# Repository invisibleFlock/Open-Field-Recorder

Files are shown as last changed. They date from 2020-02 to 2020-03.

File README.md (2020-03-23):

Welcome to the project page for the OFR

# What is OFR:

OFR is the Open Field Recorder created by Invisible Flock (and friends). 

With support and in collaboration with Bournemouth University and Professor Amanda H Korstjens from [LEAP](https://go-leap.wixsite.com/home/amanda-korstjens).

It is an open hardware and software platform for remote long form bio-acoustic recording. 

It is created for *sound artists, conservationists, scientist* and anyone who wants or needs to record audio and environmental data for long periods of time in inhospitable environments. 

It is modular, hackable, meshable and useful in a wide series of situations and applications.

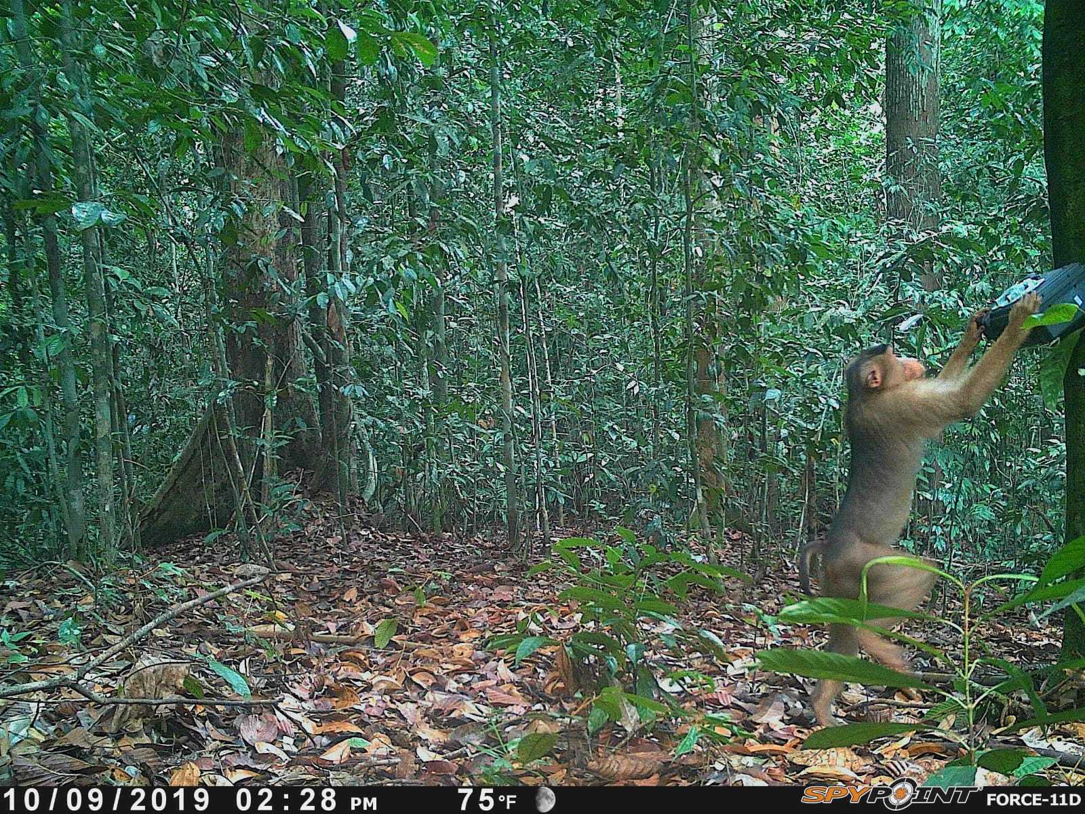
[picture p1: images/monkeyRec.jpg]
monkey with REcorder


# Why does it exit:

The OFR was created by Invisible Flock to solve a specific need we had whilst recording large sections of a rainforest in Sumatra. 

We needed recorders that would function in the difficult conditions of the forest for long periods of time in order to monitor the biodiversity of the area and that we could sync together to create large scale multichannel sound installations with audio quality as close to our main field recorders as possible.

The OFR for us was an attempt to bridge a gap that was not currently being fulfilled by other products on the market allowing us to record stereo audio from high quality microphones that were synced via GPS. 

Whilst there are other excellent products that already exist for bio-acoustic monitoring, most notably the [audio-moth](https://www.openacousticdevices.info/), the [solo](https://solo-system.github.io/home.html), and the [swift](https://www.birds.cornell.edu/ccb/wp-content/uploads/2016/09/SWIFT-SD-Card-Formatting-Protocol.pdf) none provided us with the specifics we wanted for this project but you may find they are good fit for you depending on your aims.

# What's inside it:

Expand ability and flexibility were important for us in this design and was the ability for other users to build on it and hack the recorder into their own needs. Version 1.1 is built on the [Spresense](https://developer.sony.com/develop/spresense/) a multicore development board platform by Sony which is programmable via the Arduino IDE.

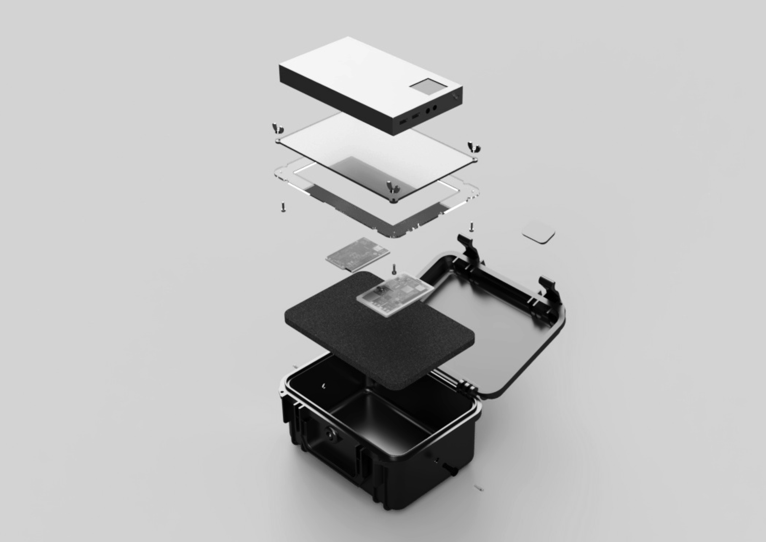
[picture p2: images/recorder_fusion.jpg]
exploded view


# So what can i do with it:

You can record the sound of landscapes in near studio quality for long periods of time day and night in all weather conditions and use GPS and analogue sensors to sync multiple recorders and data readings over time and space.

# Give me some specs:

Version 1.1 of the OFR:

- 2 to 4 channel audio
- 48khz to 198khz audio quality
- time and location sync via GPS to enable meshing of multiple recorders
- sensor logging to sync analogue sensor data points to audio files
- options for multiple budgets and microphone quality (ranging from cheap electrec mics to DPA 4060)
- phantom power 
- theoretical running time of 7 days (dependent on specs used and batteries employed)
- custom shield for extra robustness and direct tangible access to key parameters
- design for inhospitable terrain able to withstand tropical rain storms and sub zero temps

# What are you offering on here:

We do not currently sell the OFR as this would be neither cost effective for us or for you and neither would it be practical for us as we are a small studio whose main output is not product manufacture. 

Instead through this site we are working towards offering the full spec and design files for the OFR, including the CAD files for the box interior, the schematics for the shield, the codebase for creating and running your own version, a software interface for controlling and setting up your recorders and a willingness to engage and share knowledge with you in whatever project you embark on with the OFR.  

This is all provided free (as in both beer and speech) but would appreciate a mention or shoutout as we are hoping to build a community around the creative use of the OFR.

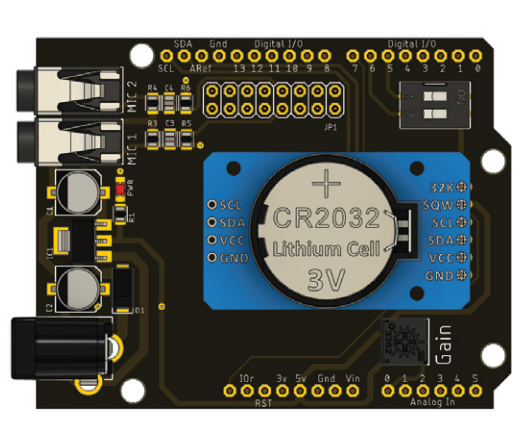
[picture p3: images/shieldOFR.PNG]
shield


# How do i use it:

Right now getting a build of your own up and running would require a bit of work on your part but we are here to help with that. In the first instance you will need to head over the [hardware](hardware/hardwareReadme.md) page which lists and explains the next steps. We are working to make the time and effort needed to get you up and running with the OFR system as easy as possible so you can get out in the field with it.

The project and the code is available on the github although at the time of writing we cannot be certain that it is a working version - over the next month we will get all of this documentation up to scratch and ready to flash onto your own OFR system.

# What are the future plans:

Future versions of the OFR will hopefully offer other platforms to run the OFR on as well as provide longer recording time and more i/o options. 

We are currently developing the shield (pictured above) which will increase the OFR's robustness in the field as well as providing physical tangible control over some key parameters of the recorder. We are developing this with our friends at [Digital Nativ](https://www.instagram.com/digitalnativ/) based in Jakarta. We hope that we will be able to offer the shields to  purchase in mid/late 2020. 

We are also working closely with our friend and long time collaborator Romit Raj from design agency [Quicksand](http://quicksand.co.in/) who is working to develop a new ML based detection and bio-auditing system and we hope to be able to release a build of the OFR fine tuned to interface and provide the best possible results with his system. 

# Where is it being used at moment:

The OFR has been deployed in Sumatra in 2019 and will  return there in mid 2020 to help monitor and establish an elephant migration corridor. It is being used in the sate of Karnataka in India where it is similarly being used on farms where human elephant conflict is a recurring issue. Later in 2020 it will be deployed across the North of Finland to record the sound of the yearly freeze as part of an ongoing project with the Sub Zero collective of artists and scientists working on the edge of the artic. Hopefully we can keep this list updated and growing.

# Can i hear what it sounds like:

Yes:
[A loud monkey cackle](/soundSample/cackle-veryloud-box1.wav).
[a storm](/soundSample/THUNDERSTORM-CLIP-BOX8.wav).
[and an orangutan](/soundSample/O-TANG-CLIP.wav).

All of these were recorded in Sumatra in 2019.

# Who else is part of this project:

The OFR was first designed and created as part of a collaboration between Invisible Flock and research undertaken by academics from [LEAP](https://go-leap.wixsite.com/home) specifically Amanda H Korstjens and Helen Slater and their ongoing research through Bournemouth University in the Leuser Ecosystem.

If you have any questions about the OFR, using it, deploying it or anything generally please do not hesitate to get in touch.

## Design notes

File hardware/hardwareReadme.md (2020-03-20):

This is the hardware section of the OFR project, here we'll talk you through all the components and process involved in building and assembling your own OFR system. Currently it may not be feasible for you to build your own as we may be missing resources or info but this is a living project and we will keep it updated.

# What does the OFR run on?:

The brains of the OFR system in the [Spresense](https://developer.sony.com/develop/spresense/specifications) board by Sony so you will need one of these before you can do anything else.

in the UK you can get them from [RS](https://uk.rs-online.com/web/p/processor-microcontroller-development-kits/1783376/)

In theory that would be all you need to get started using the cheap on board NEN mic but with the OFR part of what we wanted was the achieve audio as close as possible to what we get with our traditional field recorders.

As such we have designed the OFR to run in stereo with two omni microphones. The full spec is th two [DPA 4060s](https://www.dpamicrophones.com/lavalier/4060-series-miniature-omnidirectional-microphone) these are almost industry standard when it comes to field recording and are used by all the greats, obviously with a cost overhead. More affordable would be two [primo capsules](https://micbooster.com/primo-microphone-capsules/8-primo-em172.html). 

If using the the DPA 4060s you will need phantom power. Although technically 48v the mics themselves only need 9v so using this little  bit of circuitry will let you run your two DPA straight into the Spresense.

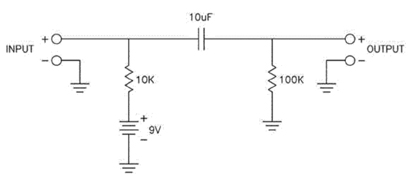
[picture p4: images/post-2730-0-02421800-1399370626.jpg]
phantom circuit


If using the Primos then no need for phantom power.

This in theory is all you would need to get a OFR system running - the board and mics. The board has GPS inbuilt and all you need is an SD card.

To record outside you will of course need an enclosure. There are a lot of options out there. We have a design for a very robust build designed for highly inhospitable environments. it's based around the [cases by peli](https://uk.rs-online.com/web/p/flight-cases-equipment-cases/2974874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) and when it comes to weatherproofing you do get what you pay for. 

We will put together a comprehensive list of instructions with images and step by step assembly guide soon.

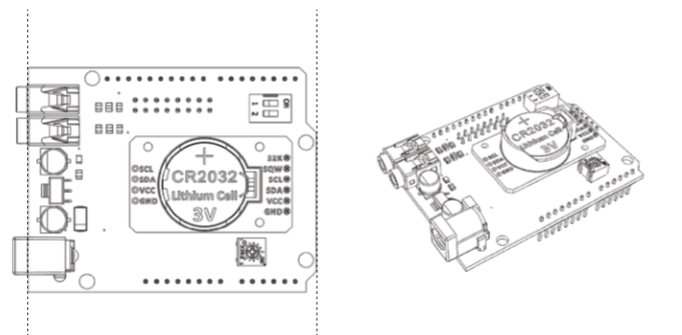
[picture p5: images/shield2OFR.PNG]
shield2


# Shield:

The OFR shield is our new and exciting development in the OFR. Its built with our friends over at Digital Nativ and is designed to increase both the robustness of the recorder in the field and the speed at which new builds can get up and running. It does this by minimising the amount of assembly but also the amount of loose and moving parts in the final assembly, meaning less to get knocked and corroded.

The shield will further provide you with tangible physical controls over some key parameters such as Gain, Audio Quality and toggling the GPS on and off for indoor or outdoor use.

The current international situation has slowed down the development of the board but we expect to have prototype builds out late summer 2020 and have a limited amount available for sale late 2020.

COMInG SOON:

*a step by step build tutorial and videos of how to assemble your own OFR*

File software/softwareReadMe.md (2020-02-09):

This is the readme file for the software folder.

This folder will contain the files for the spresense board as well as the interface files - we may not be able to host the executables on here but we can put the source files for the OF proejct

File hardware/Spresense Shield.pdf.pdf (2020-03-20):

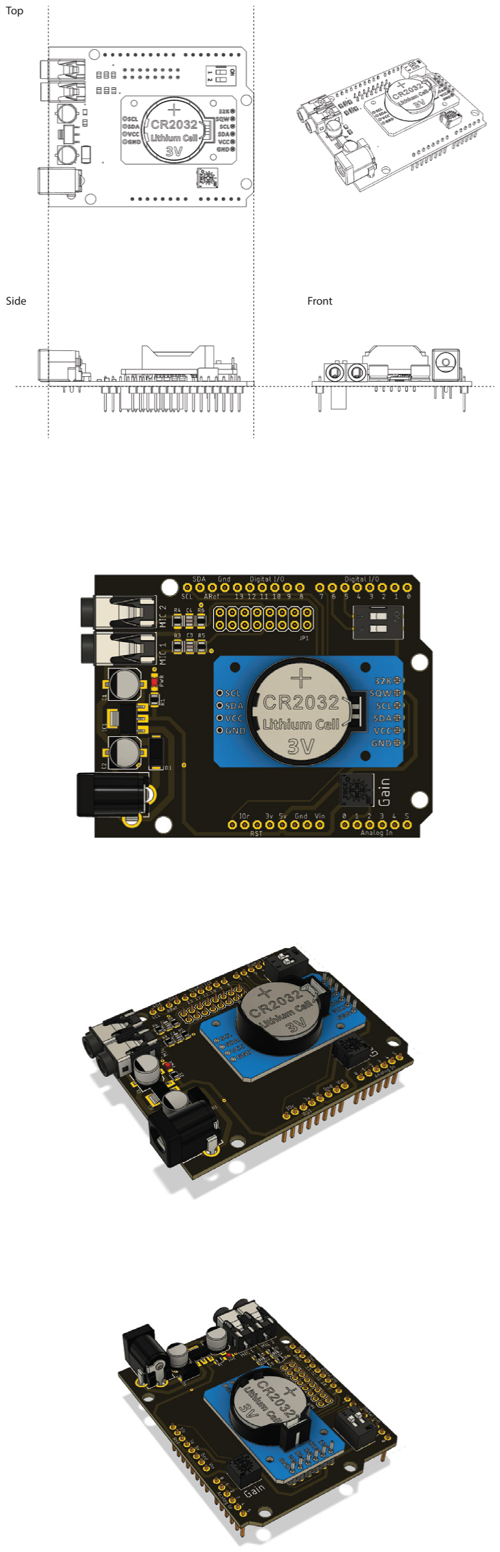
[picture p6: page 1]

Top

Side | Front

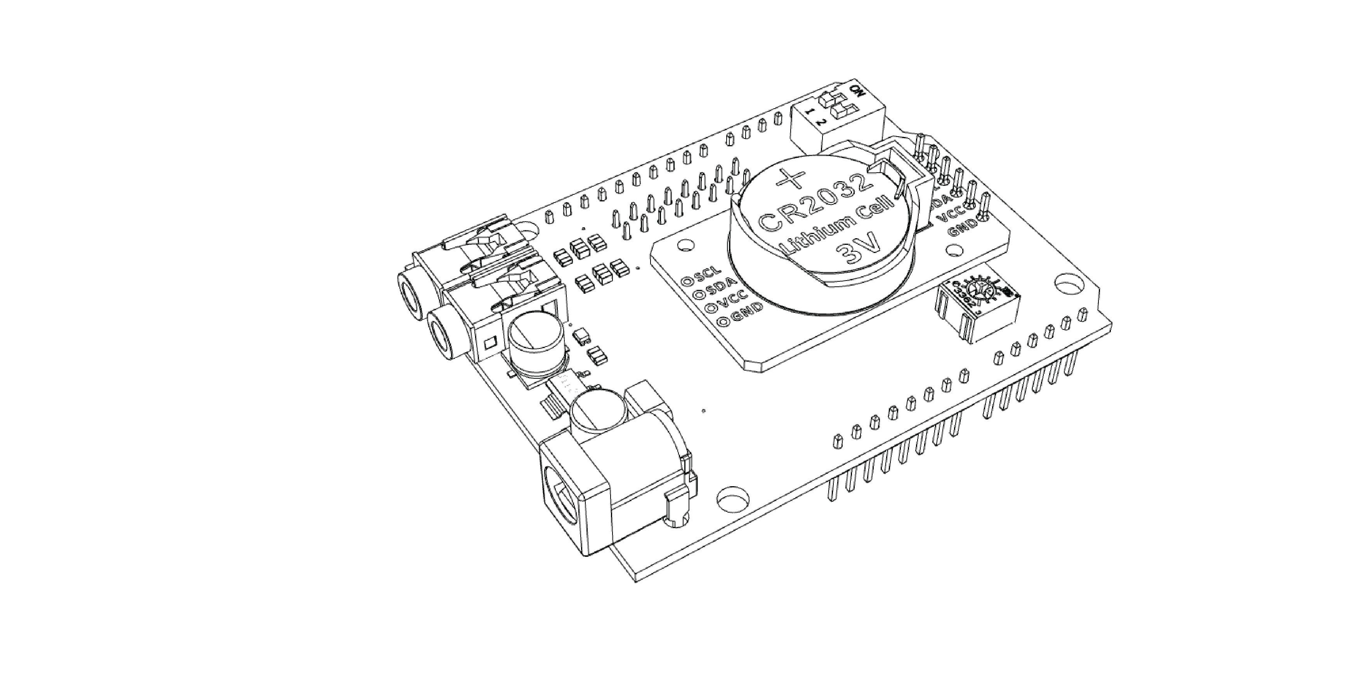
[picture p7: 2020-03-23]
hardware/Images/Iso.png

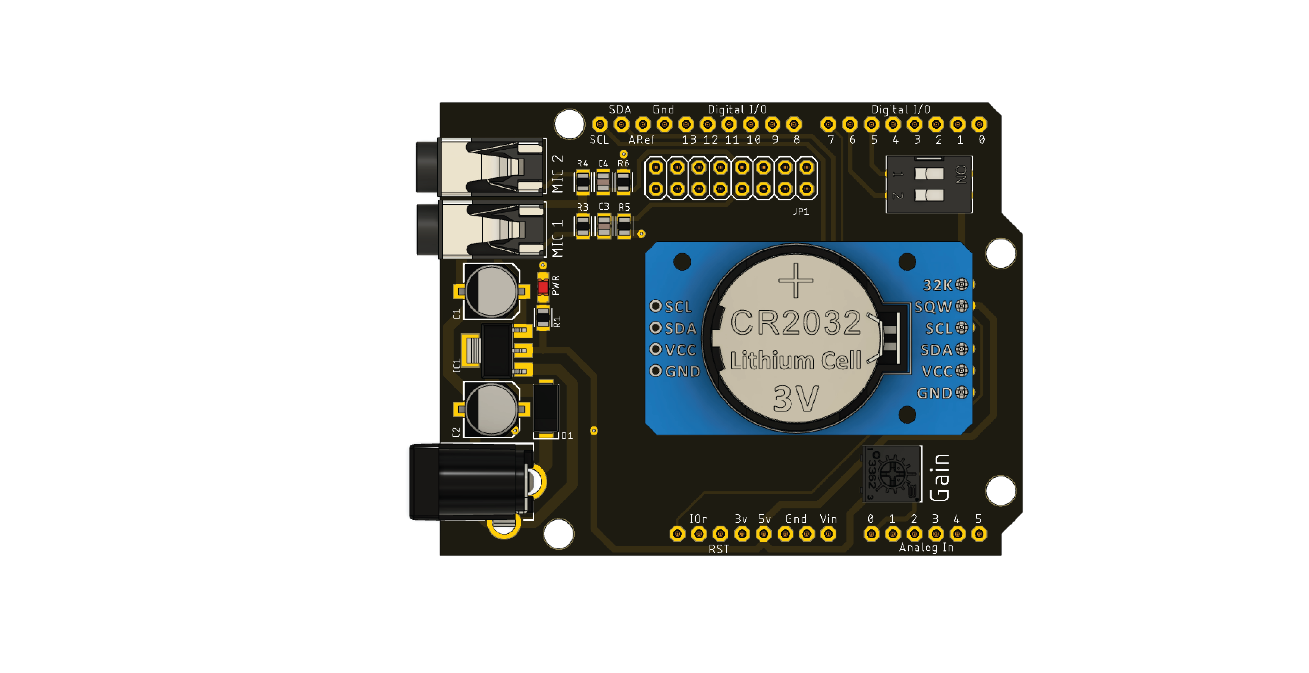
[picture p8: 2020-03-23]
hardware/Images/Frame1.png

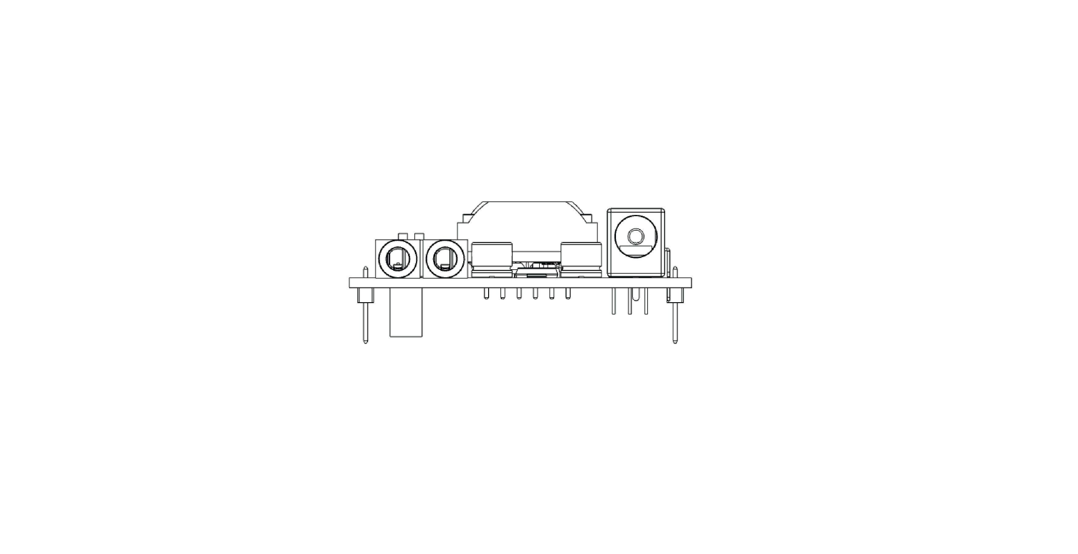
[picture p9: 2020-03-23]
hardware/Images/Front.png

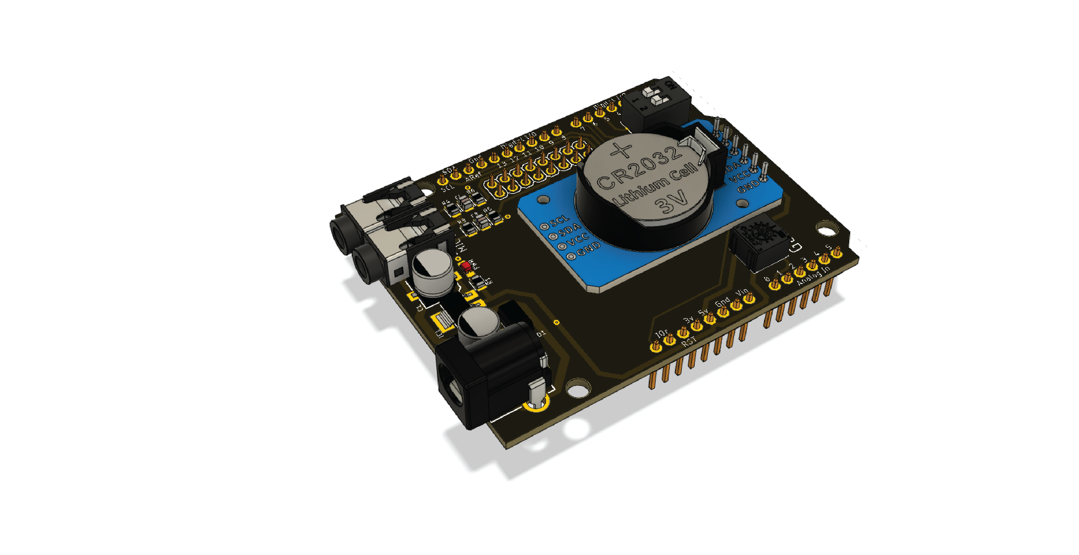
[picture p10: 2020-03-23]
hardware/Images/Frame2.png

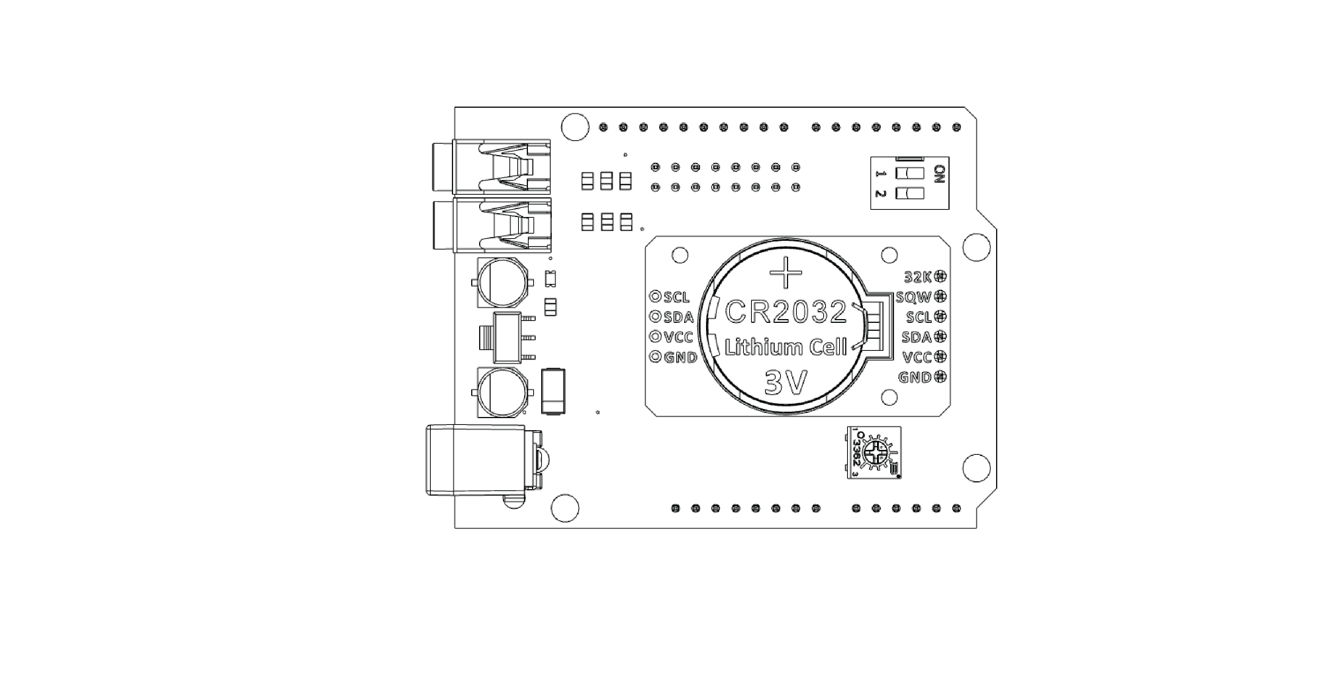
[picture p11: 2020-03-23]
hardware/Images/Top.png

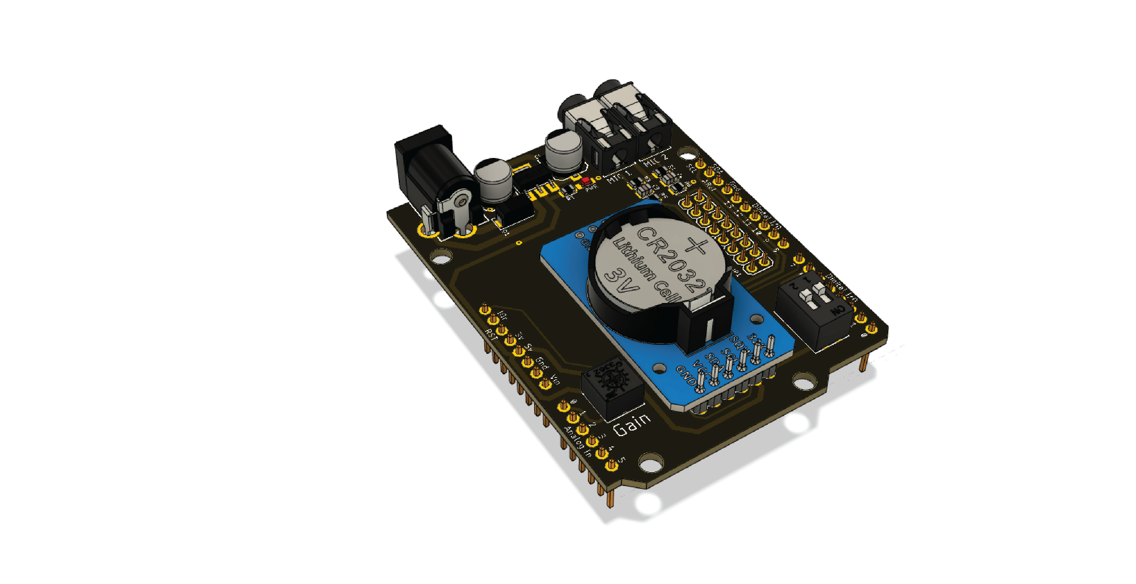
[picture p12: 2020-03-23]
hardware/Images/Frame3.png

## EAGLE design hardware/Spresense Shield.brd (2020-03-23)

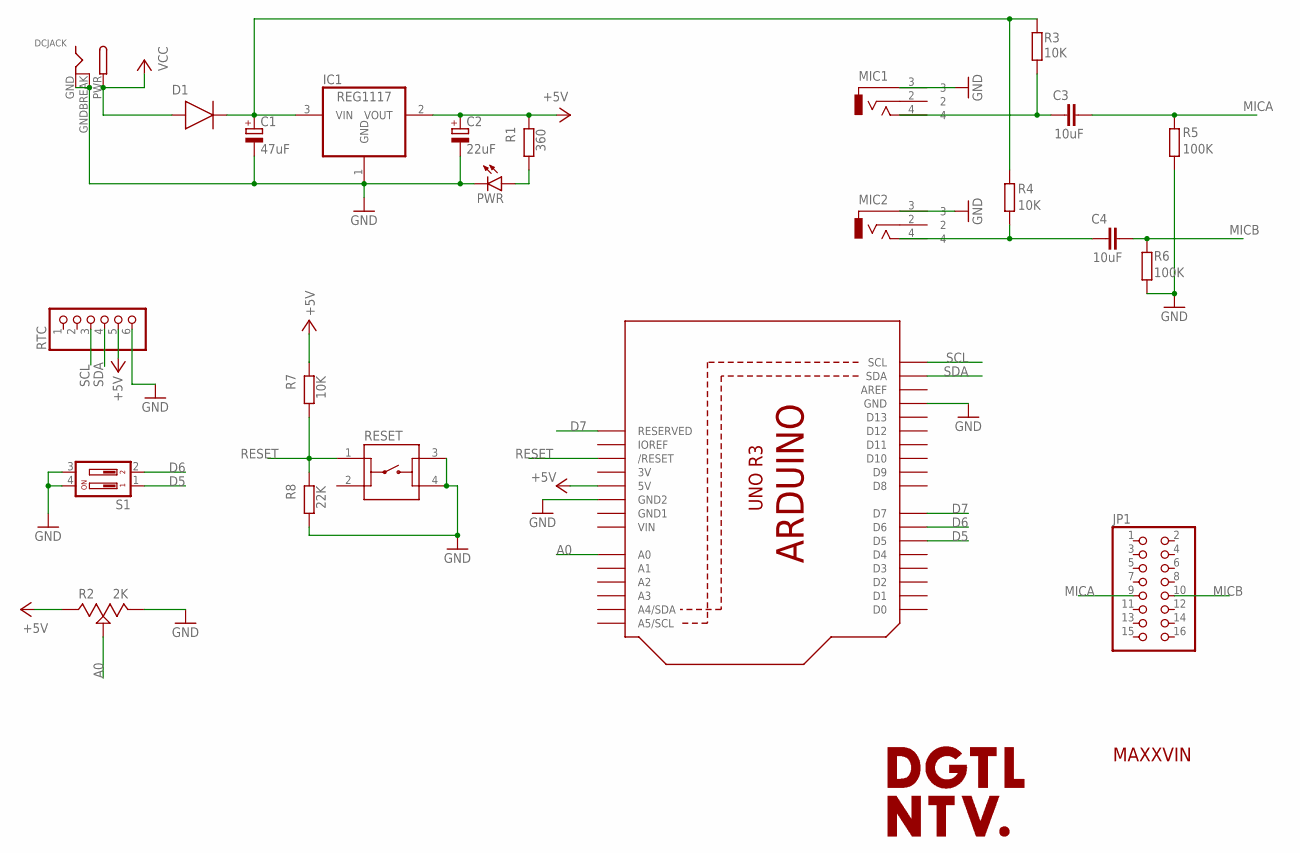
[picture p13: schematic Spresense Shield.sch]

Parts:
C1: 47uF; 153CLV-0605
C2: 22uF; 153CLV-0605
C3, C4: 10uF; CAPC2012X110
D1: DIODEDO-214AC(SMA); DIOM5226X290N
DCJACK: DCBARRELPTH; DCJACK_2MM_PTH
IC1: REG1117; SOT223
JP1: PINHD-2X8; 2X08
MIC1, MIC2: PJ-320F
PWR: LEDCHIP-LED0805; CHIP-LED0805
R1: 360; RESC2012X65
R2: 2K; 3362P-1-103LF
R3, R4, R7: 10K; RESC2012X65
R5, R6: 100K; RESC2012X65
R8: 22K; RESC2012X65
RESET: 1825910-6
RTC: PINHD-1X6; 1X06
S1: DS02; DS-02
U1: ARDUINOR3-DIMENSION; ARDUINOR3

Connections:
3V: U1.3V
+5V: C2.+, IC1.2 (VOUT), R1.1, R2.3, R7.1, RTC.5, U1.5V
A0: R2.2, U1.A0
D5: S1.1, U1.D5
D6: S1.2, U1.D6
D7: U1.D7, U1.RESERVED
GND: C1.-, C2.-, DCJACK.GND, DCJACK.GNDBREAK, IC1.1 (GND), MIC1.3, MIC2.3, PWR.C, R2.1, R5.2, R6.2, R8.2, RESET.3, RESET.4, RTC.6, S1.3, S1.4, U1.GND, U1.GND2
GND1: U1.GND1
MICA: C3.2, JP1.9, R5.1
MICB: C4.2, JP1.10, R6.1
unnamed: C4.1, MIC2.4, R4.2
unnamed: C1.+, D1.2 (C), IC1.3 (VIN), R3.1, R4.1
unnamed: C3.1, MIC1.4, R3.2
unnamed: PWR.A, R1.2
RESET: R7.2, R8.1, RESET.1, U1.RESET (/RESET)
SCL: RTC.3, U1.SCL
SDA: RTC.4, U1.SDA
VCC: D1.1 (A), DCJACK.PWR
VIN: U1.VIN

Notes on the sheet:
MAXXVIN

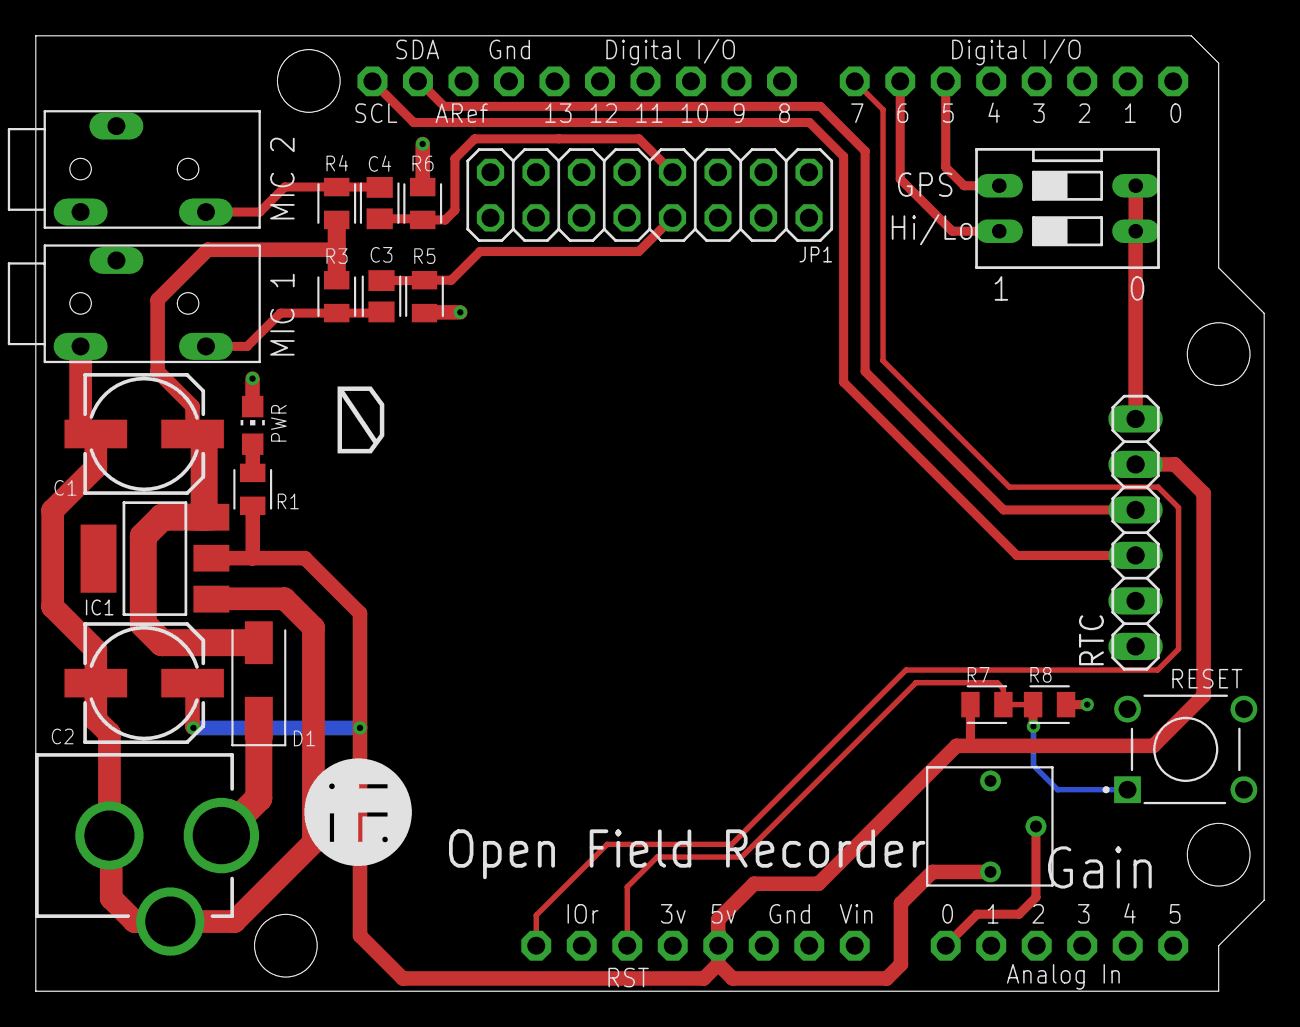
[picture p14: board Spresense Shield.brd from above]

Board: 2 copper layers, 68.6 x 53.3 mm, 25 parts (0 on the bottom side), 16 nets.

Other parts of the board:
U$1: IF_SOLID_LOGO_TOP_6MM
U$4: D_LOGO_TOP_2.7MM

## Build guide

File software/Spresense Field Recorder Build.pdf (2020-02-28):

1. Delete Spresense folder from library
2. Download and install the custom SDK and install using these instructions https://developer.sony.com/develop/spresense/docs/arduino_set_up_en.html#_manual_i nstallation (https://developer.sony.com/develop/spresense/docs/arduino_set_up_en.html#_manual_installation)
3. Upload ‘Spresense_Field_Recorder_SubCore_1’ to SubCore 1 of the Spresense
4. Upload ‘Spresense_Field_Recorder_Main_Core’ to Main Core of the Spresense
5. The mic inputs should be in the 4th row from the bottom on the jumpers with the ground on either of the jumpers on the second to bottom row

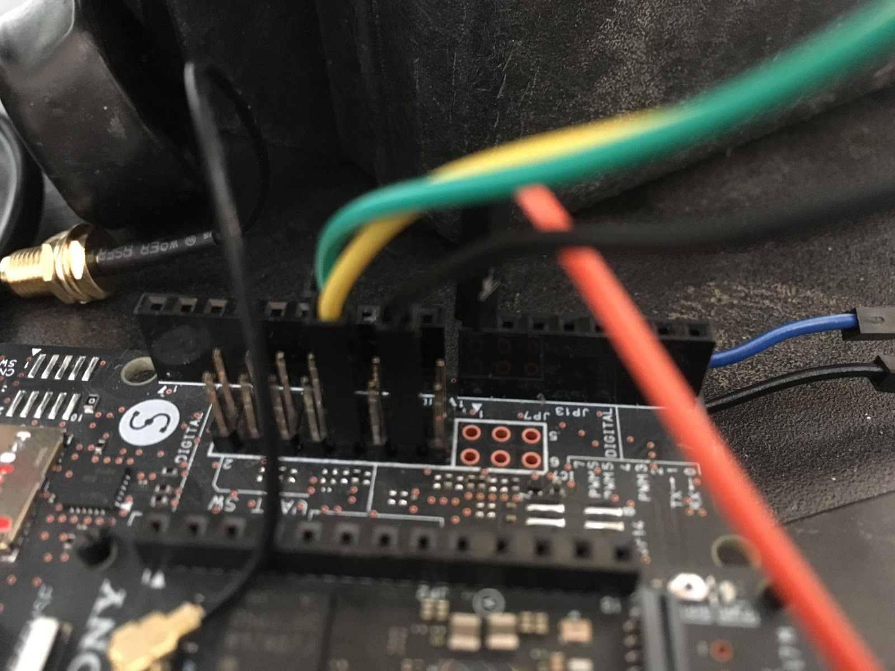
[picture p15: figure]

6. GPIO 7 needs to be connected to RST to make it reset
7. When powered up, LED3 should come on first within 30seconds and stay on for up to a minute while it finds GPS. If this doesn’t happen, press the small reset button.
8. A single light will start flashing while it’s recording.
9. Other light codes
LED0 on constant - File Open Error
LED1 on constant - Error reading audio
LED2 on constant - File end error
All lights flashing - SD Card full

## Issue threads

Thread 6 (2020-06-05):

Beta Testing

TechnoHomesteader, 2020-06-05:
This is a great project! I'd love to build one once the full specs are available. If I wanted to get a jump on working with the dev board - is the correct part the Sony Spresense CXD5602? Also, will I need the expansion board as part of the intended build?

I'm also quite interested in the potential for an Ambisonic capture option. Has any thought been given toward using the 8 digital input channels on the spresense to enable second order capture?

benIflock, 2020-06-11:
Hi !
thanks for getting in touch and sorry its taken so long to respond

to get going with it you would need both the core srpesense board and also
the extension board as that has the audio inputs etc - we also have a
custom sdk that we got from sony - not 100% sure if its now included in the
official release - which was to fix some bugs we were getting with the
board dropping out or freezing up as it recorded - one of the biggest
issues we had was a constant buffer overflow issue - it was hard to
completely diagnose because we were working with 256gb cards (32gb cards
for long form audio doesn't really make much sense) and the board works
with caars that are fat32 so technically sony didn't want to officially
troubleshoot a 256 card - but it does work now

in terms of ambisionic we have definitely thought about it - at the moment
we are doing stereo and get a really nice binaural image from two omni-mics
mounted either side of the enclosures we use - we had been looking at
https://www.thingiverse.com/thing:2568132 but simply haven't got around to
testing it yet

devevlopment on this whole project has slowed down a bit with covid - we
had some custom shields int he works but we've also hit the brakes on that
but hoping to get it up and running again soon - let me know if you want to
try out the code or any components of it - to be honest there is nothing
hugely technically complex going on a lot of it is just in  the execution

cheers

best

Ben

On Fri, 5 Jun 2020 at 02:10, TechnoHomesteader <notifications@github.com>
wrote:

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

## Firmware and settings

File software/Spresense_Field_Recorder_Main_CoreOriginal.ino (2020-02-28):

#include <SDHCI.h>
#include <Audio.h>
#include <RTC.h>
#include <MP.h>  
#include <GNSS.h>

#define MY_TIMEZONE_IN_SECONDS (12 * 60 * 60)
#define TIME_HEADER 'T'

SDClass theSD;
AudioClass *theAudio;
SpGnss Gnss;
File myFile;

int noChar = 0;
int counter = 0;
String fileCounter ="";
char fileCounterChar = "";
int fileCounterInt = 0;
int fileCounterCharInt = 0;
bool updateTime = false;
bool ErrEnd = false;

//this has been halved for stereo
static const int32_t recoding_frames = 18750;
static const int32_t recoding_size = recoding_frames * 6144; /* 4ch, 16bit, 768sample */

/**
 * @brief Audio attention callback
 *
 * When audio internal error occurc, this function will be called back.
 */

static void audio_attention_cb(const ErrorAttentionParam *atprm)
{
  Serial.println("Attention!");

  if (atprm->error_code >= AS_ATTENTION_CODE_WARNING)
  {
    ErrEnd = true;
  }
}

int setup_audio()
{
  err_t err;

  Serial.println("Setup Audio Library");

  theAudio = AudioClass::getInstance();

  err = theAudio->begin(audio_attention_cb);
  if (err != AUDIOLIB_ECODE_OK) {
    Serial.println("theAudio->begin error");
    return -1;
  }

//uncomment this code for 192000Hz sample rate
 /* err = theAudio->setRenderingClockMode(AS_CLKMODE_HIRES);
  if (err != AUDIOLIB_ECODE_OK) {
    Serial.println("theAudio->setRenderingClockMode error");
    return -1;
  }*/

  err = theAudio->setRecorderMode(AS_SETRECDR_STS_INPUTDEVICE_MIC, 160, 327680);
  if (err != AUDIOLIB_ECODE_OK) {
    Serial.println("theAudio->setRecorderMode error");
    return -1;
  }
  sleep(1);

  /*
   * Initialize filetype to stereo wav with 48 Kb/s sampling rate
   * Search for WAVDEC codec in "/mnt/sd0/BIN" directory
   */

  theAudio->initRecorder(AS_CODECTYPE_WAV, "/mnt/spif/BIN", AS_SAMPLINGRATE_48000, AS_CHANNEL_STEREO);
  if (err != AUDIOLIB_ECODE_OK) {
    Serial.println("theAudio->initRecorder error");
    return -1;
  }

  return 0;
}

int start_record()
{
  err_t err;

  GPS_update();

  if (Serial.available())
  {
    if (Serial.find(TIME_HEADER))
    {
      uint32_t pctime = Serial.parseInt();
      RtcTime rtc(pctime);
      RTC.setTime(rtc);
      Serial.println("timeupdated");
    }
  }

  if(fileCounterInt >= 1100){
    Serial.println("SD Card Full");
    MP.Send(1, 7, 1);
    while(1);
  }

  fileCounterInt = fileCounterInt + 1;
  theSD.remove("counter.txt");
  
  myFile = theSD.open("counter.txt", FILE_WRITE);
  if (!myFile)
  {
    Serial.println("File writing open error");
    return -1;
  }
  myFile.print(fileCounterInt);
  Serial.print("Written to file - ");
  Serial.println(fileCounterInt);
  myFile.close();
  
  RtcTime now = RTC.getTime();

  char filename[20] = {0};
  sprintf(filename, "M%02dD%02dH%02dM%02dS%02d.wav", now.month(), now.day(), now.hour(), now.minute(), now.second());
  Serial.println(filename);

  /* Open file for data write on SD card */
  myFile = theSD.open(filename, FILE_WRITE);
  if (!myFile)
  {
    Serial.println("File open error");
    MP.Send(1, 3, 1);
    return -1;
  }

  err = theAudio->writeWavHeader(myFile);
  if (err != AUDIOLIB_ECODE_OK) {
    Serial.println("theAudio->writeWavHeader error");
    myFile.close();
    return -2;
  }
  MP.Send(4, 1, 1);
  err = theAudio->startRecorder();
  if (err != AUDIOLIB_ECODE_OK) {
    Serial.println("theAudio->startRecorder error");
    myFile.close();
    return -3;
  }


  Serial.println("Recording Start!");

  return 0;
}

void stop_record()
{
  theAudio->stopRecorder();
  theAudio->closeOutputFile(myFile);
  myFile.close();
  counter++;

  Serial.println("End Recording");
  MP.Send(4, 2, 1);
}

void GPS_update()
{
  /* Wait for GNSS data */
  //Serial.println("Gnss.waitUpdate");
  if (Gnss.waitUpdate())
  {
    SpNavData NavData;

    /* Get the UTC time */
    Gnss.getNavData(&NavData);
    SpGnssTime *time = &NavData.time;

    /* Check if the acquired UTC time is accurate */
    if (time->year >= 2000)
    {
      RtcTime now = RTC.getTime();
      /* Convert SpGnssTime to RtcTime */
      RtcTime gps(time->year, time->month, time->day,
                  time->hour, time->minute, time->sec, time->usec * 1000);
      updateTime = true;
#ifdef MY_TIMEZONE_IN_SECONDS
      /* Set the time difference */
      gps += MY_TIMEZONE_IN_SECONDS;
#endif
      int diff = now - gps;
      if (abs(diff) >= 1)
      {
        RTC.setTime(gps);
        Serial.println("Gnss Updated");
      }
    }
  }
}
void setup()
{
  
  int ret;

  Serial.begin(115200);

  /* Wait HW initialization done. */
  sleep(3);

  ret = Gnss.begin();
  if (ret != 0)
  {
    Serial.println("Gnss.begin error");
    assert(ret == 0);
  }

  ret = Gnss.start(COLD_START);
  if (ret != 0)
  {
    Serial.println("Gnss.start error");
    assert(ret == 0);
  }

  ret = MP.begin(1);
  if (ret < 0)
  {
    Serial.println("MP.begin error");
  }

  RTC.begin();

  ret = setup_audio();
  if (ret < 0)
  {
    Serial.println("setup_audio error");
    assert(ret == 0);
  }

  ledOn(LED3);
  
  Serial.println("Waiting for GPS");
  while (!updateTime)
  {
    GPS_update();
  }

  ledOff(LED3);
  MP.Send(1, 6, 1);
    
    myFile = theSD.open("counter.txt", FILE_READ);
  if (!myFile)
  {
    Serial.println("File reading open error");
    return -1;
  }

  while (myFile.available()){
    fileCounterChar = myFile.read();
    fileCounter += fileCounterChar;
    fileCounterInt = 0;
  }
  noChar = fileCounter.length();
  if(noChar >= 1){
  for(int i=0; i <= (noChar-1) ; i++){
    fileCounterCharInt = (fileCounter[i] - '0');
    fileCounterCharInt = fileCounterCharInt*pow(10,(noChar - (i+1)));
    //Serial.print("Char - ");
    //Serial.println(fileCounterCharInt);
    fileCounterInt = fileCounterInt + fileCounterCharInt;
    //Serial.print("file Counter - ");
    //Serial.println(fileCounterInt);
  }
  }else{
    fileCounterInt = 0;
  }
    //fileCounterInt = fileCounter - '0';
    Serial.print("Read from file - ");
    Serial.println(fileCounterInt);

    myFile.close();
}

void loop()
{
  int ret;
  err_t err = AUDIOLIB_ECODE_OK;

  Serial.println("Start record!");

  ret = start_record();
  if (ret != 0) {
    Serial.print("start_record error = ");
    Serial.println(ret);
    sleep(1);
    return;
  }

  /* recording end condition */
  //Serial.println("Read and save record!");

  while (theAudio->getRecordingSize() < recoding_size && err == AUDIOLIB_ECODE_OK && !ErrEnd)
  {
    /* Read frames to record in file */
    err = theAudio->readFrames(myFile);
  }

  sleep(1);

  //Serial.println("Stop record!");

  stop_record();

  if (err != AUDIOLIB_ECODE_OK)
  {
    Serial.println("theAudio->readFrames error");
    MP.Send(1, 4, 1);
  }

  if (ErrEnd)
  {
    Serial.println("Error End");
    MP.Send(1, 5, 1);
    ErrEnd = false;
  }
}

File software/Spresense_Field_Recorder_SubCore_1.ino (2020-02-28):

#include <MP.h>
int LED = 0;
int led0 = 0;
int led1 = 0;
int led2 = 0;
int led3 = 0;
int ledall = 0;
unsigned long timer = 0;
int starter = 0;

void setup() {
  pinMode(7,OUTPUT);
  digitalWrite(7,HIGH); //initialise reset pin
  
  int ret = 0;

  ret = MP.begin();  //start multicore processing
  if (ret < 0) {
    errorLoop(2);
  }
MP.RecvTimeout(MP_RECV_POLLING);
}
void errorLoop(int num)  //if multicore doesn't start, flash led0
{
  int i;

  while (1) {
    for (i = 0; i < num; i++) {
      ledOn(LED0);
      delay(300);
      ledOff(LED0);
      delay(300);
    }
    delay(1000);
  }
}
void loop() {
  int      ret;
  int8_t   msgid;
  uint32_t msgdata;
  
  ret = MP.Recv(&msgid, &msgdata); // receive message from Main Core
  
if(msgdata == 6 && starter == 0){  // start core 1 checking for timeout on Main Core
  starter = 1;
  timer = millis();
}


if(starter == 1){
    if(msgdata == 1){         // on msg 1 (recording started), restart timer and change flashing LED to next LED
      timer = millis();
      if(LED == 0){
        ledOn(LED0);
        led0 = 1;
         (LED = 1);
      }
      if(LED == 2){
        ledOn(LED1);
        led1 = 1;
        (LED = 3);
      }
      if(LED == 4){
        ledOn(LED2);
        led2 = 1;
        (LED = 5);
      }
    }


    
    if(msgdata == 2){           // on msg 2 (recording finished), turn off flashng LED and reset timer
      timer = millis();
      if(LED == 1){
        ledOff(LED0);
        led0 = 0;
        (LED = 2);
      }
      if(LED == 3){
        ledOff(LED1);
        led1 = 0;
        (LED = 4);
      }
      if(LED == 5){
        ledOff(LED2);
        led2 = 0;
        (LED = 0);
      }
    }
    if(msgdata == 3){     // on msg 3 (file open error) turn on LED0
      led0 = 0;
      led1 = 0;
      led2 = 0;
      led3 = 0;
      ledOn(LED0);
      ledOff(LED1);
      ledOff(LED2);
      ledOff(LED3);
    }

    if(msgdata == 4){     // on msg 4 (read frames error) turn on LED1
      led0 = 0;
      led1 = 0;
      led2 = 0;
      led3 = 0;
      ledOff(LED0);
      ledOn(LED1);
      ledOff(LED2);
      ledOff(LED3);
    }

    if(msgdata == 5){     // on msg 5 (Error End) turn on LED2
      led0 = 0;
      led1 = 0;
      led2 = 0;
      led3 = 0;
      ledOff(LED0);
      ledOff(LED1);
      ledOn(LED2);
      ledOff(LED3);
    }

    if(msgdata == 7){     // on msg 7 (SD Card full) flash all LEDs
      led0 = 0;
      led1 = 0;
      led2 = 0;
      led3 = 0;
      ledall = 1;
    }
    
    if(led0 == 1){
      ledOff(LED0);
      led0 = 2;
      delay(2000);
    }
    if(led0 == 2){
      ledOn(LED0);
      led0 = 1;
      delay(100);
    }

    if(led1 == 1){
      ledOff(LED1);
      led1 = 2;
      delay(2000);
    }
    if(led1 == 2){
      ledOn(LED1);
      led1 = 1;
      delay(100);
    }
    if(led2 == 1){
      ledOff(LED2);
      led2 = 2;
      delay(2000);
    }
    if(led2 == 2){
      ledOn(LED2);
      led2 = 1;
      delay(100);
    }
    if(led3 == 1){
      ledOff(LED3);
      led3 = 2;
      delay(2000);
    }
    if(led3 == 2){
      ledOn(LED3);
      led3 = 1;
      delay(100);
    }

    if(ledall == 1){
      ledOff(LED0);
      ledOff(LED1);
      ledOff(LED2);
      ledOff(LED3);
      ledall = 2;
      delay(2000);
      timer = millis();
    }
    if(ledall == 2){
      ledOn(LED0);
      ledOn(LED1);
      ledOn(LED2);
      ledOn(LED3);
      ledall = 1;
      delay(100);
    }
  
    if((unsigned long)(millis()-timer) >= 660000){    // if timer goes on longer than 11 minutes without being reset, turn on all LEDs and reset board
      led1 = 3;
      led2 = 3;
      led3 = 3;
      ledOn(LED0);
      ledOn(LED1);
      ledOn(LED2);
      ledOn(LED3);
      digitalWrite(7,LOW);
    }

    if((((unsigned long)(millis()-timer)) <= 660000) && led1 == 3){
      led1 = 0;
      led2 = 0;
      led3 = 0;
      ledOff(LED0);
      ledOff(LED1);
      ledOff(LED2);
      ledOff(LED3);
    }
    
}
  // put your main code here, to run repeatedly:

}

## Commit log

2020-02-28 Add files via upload
    the code for the core and the subcore as it stands now - some of the core variables have been exposed but need hooking into their relative conditional states - small chance the OFR main code might no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
2020-03-20 Add files via upload
    circuit diagram for shield
